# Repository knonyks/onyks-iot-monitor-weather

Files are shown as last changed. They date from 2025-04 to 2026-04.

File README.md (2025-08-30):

<span style="font-weight:700;font-size:40px; font-style: italic;">
    Stacja pogodowa
</span>

## Wstęp
Tematem tego projektu jest stacja pogodowa, która zbiera informację odnośnie warunków atmosferycznych i na ich podstawie wysyła dane na oficjalną stronę koła naukowego ONYKS. Stacja ta, mierzy takie wielkości jak poziom CO2, temperaturę, prędkość wiatru, wilgotność itp. (o tym dalej).

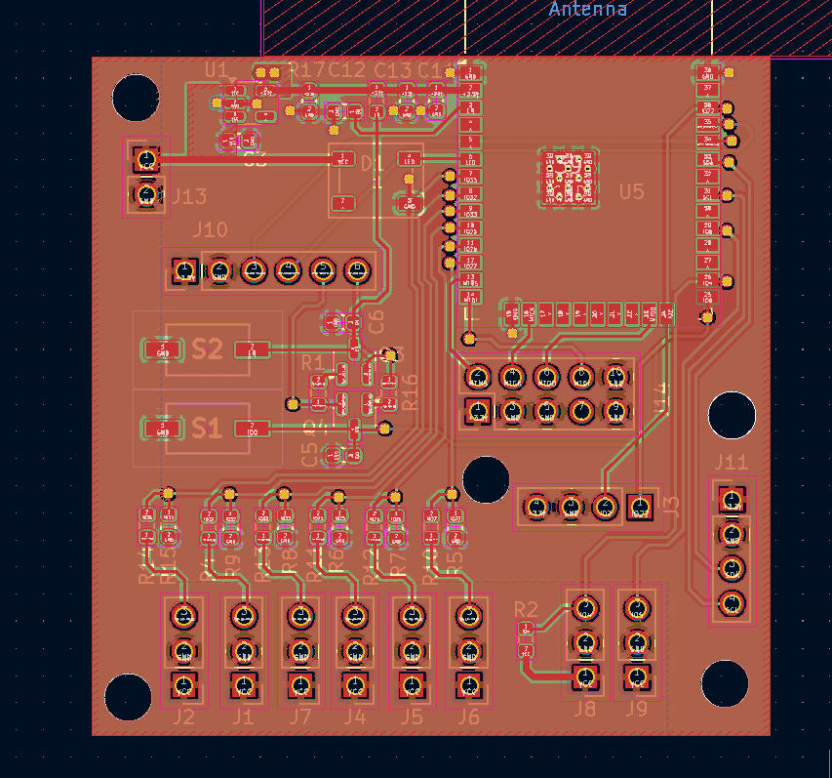
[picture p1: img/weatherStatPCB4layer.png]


## Założenia - jak to ma działać
Dane zbierane są za pomocą odpowiednich czujników a następnie przetwarzane przez mikrokontroler ESP32 - w tym projekcie użyto ESP32-WROOM-32D. Po przetworzeniu dane będą wysyłane na serwer przy użyciu WIFI, a następnie wyświetlane w odpowiedniej rubryce na głównej stronie koła naukowego ONYKS. Planowany rozmiar PCB ***100 mm x 82 mm***.

## Pomiary 

- Pomiar prędkości wiatru - polega na zmierzeniu prędkości obrotowej wału z magnesem, który jest obracany przy użyciu wiatraka. Pomiar ten będzie wykonywany za pomocą **Hallotronu** (czyli na przykład pomiar częstotliwości umownej "1" na czujniku i na podstawie tego określenie prędkości).

- Pomiar ilości opadów - wykonywany w podobny sposób co pomiar prędkości wiatru, z tą różnicą, że wałem kręcą łopatki, o konkretnej objętości. Takie koło wodne wporowadzane jest w ruch kiedy dana łopatka jest wypełniona. Obroty wału z magnesem są szczytywane za pomocą **Hallotronu**. 

- Pomiar kierunku wiatru - odbywa się również za pomocą 4 **Hallotronów** i wału obracanego wiatrowskazem. Tym razem aktywne czujniki wskazują kierunek. Do wskazania będzie 8 kierunków (na przykład pólnoc, południowy wschód itd.).

- Pomiar temperatury oraz wilgotności powietrza - odczytywane dane są z czujnika **DHT22**, który jest zamontowany w obudowie na zewnątrz stacji.

- Pomiar stężenia C02 w atmosferze - odbywa się za pomocą czujnika **SEN0219** znajdującego się bezpośrednio na PCB.

- Pomiar jakości powietrza - polega zastosowaniu czujnika **MQ135**, który jest czuły na Amoniak, gazy Siarczku, opary spowodowane spalaniem Benzenu, oraz potrafi wykrywać dym i innego rodzaju szkodliwe gazy. W czystym powietrzu czujnik ten ma niską przewodność, rośnie wraz z pojawieniem się w atmosferze substancji szkodliwych

## Obudowy oraz elementy mechaniczne

- Obudowy, będą zaprojektowane w oprogramowaniu CAD a następnie wyprodukowane za pomocą druku 3D. 

- Wały i łożyska będą kupowane w sklepie modelarskim np. *https://sklep.modelarnia.pl/*, lub budowalnym takim jak OBI czy CASTORAMA.

- Wiatrak i koło wodne będą zaprojektowane w oprogramowaniu CAD, a następnie drukowane.

- Do **Hallotronów** będą użyte drobne magnesy Neodymowe

## Schematy blokowe

###  Położenie elementów na płytce drukowanej :
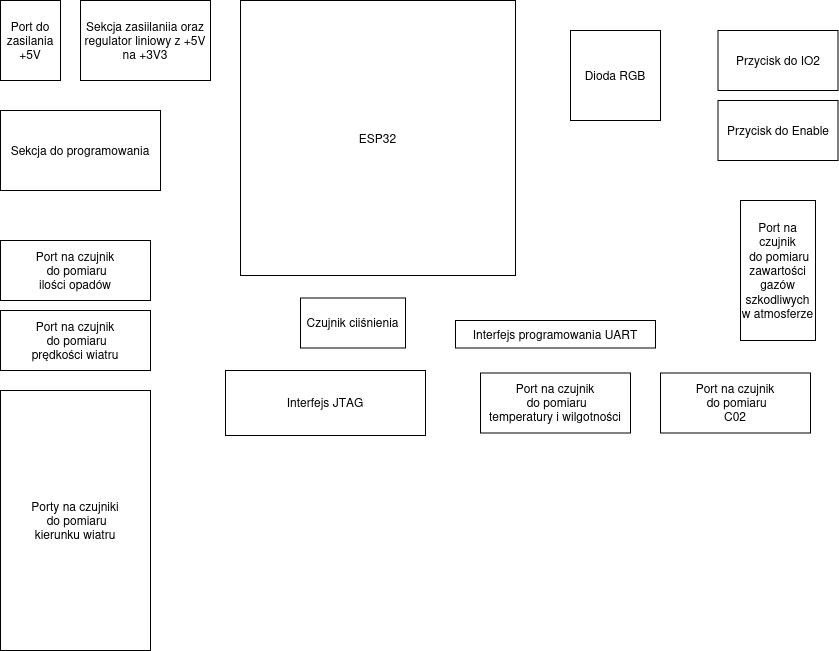
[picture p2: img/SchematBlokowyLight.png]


###  Ogólny schemat ideowy układu :
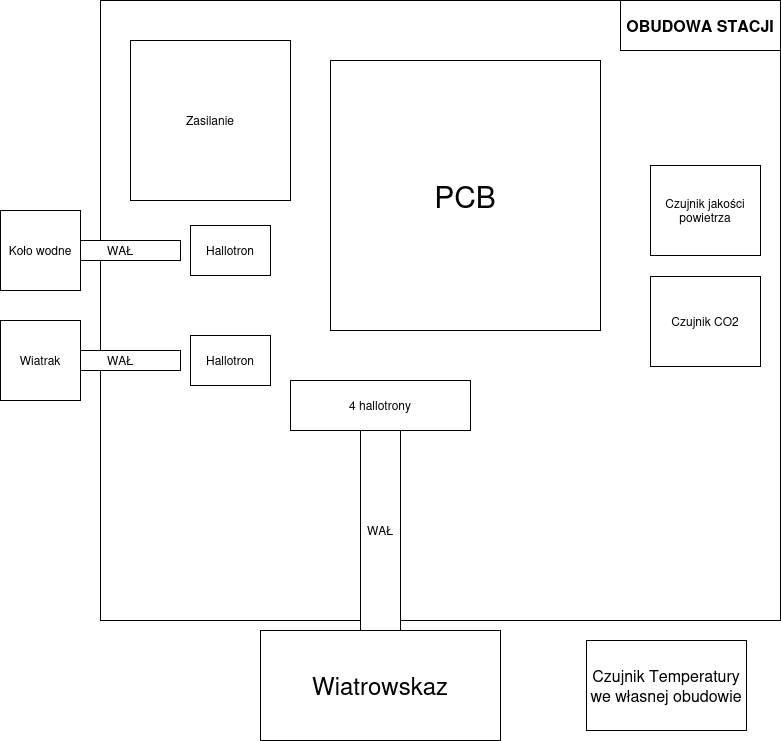
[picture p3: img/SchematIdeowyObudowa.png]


## Link do rozpiski z elementami
Tutaj stworzony jest wykaz elementów potrzebnych do złożenia danej stacji : 
https://docs.google.com/spreadsheets/d/16E9U7lwzSHfPhs8wRjM2mrblf8zyNPCpttjlwKn6Azs/edit?usp=sharing

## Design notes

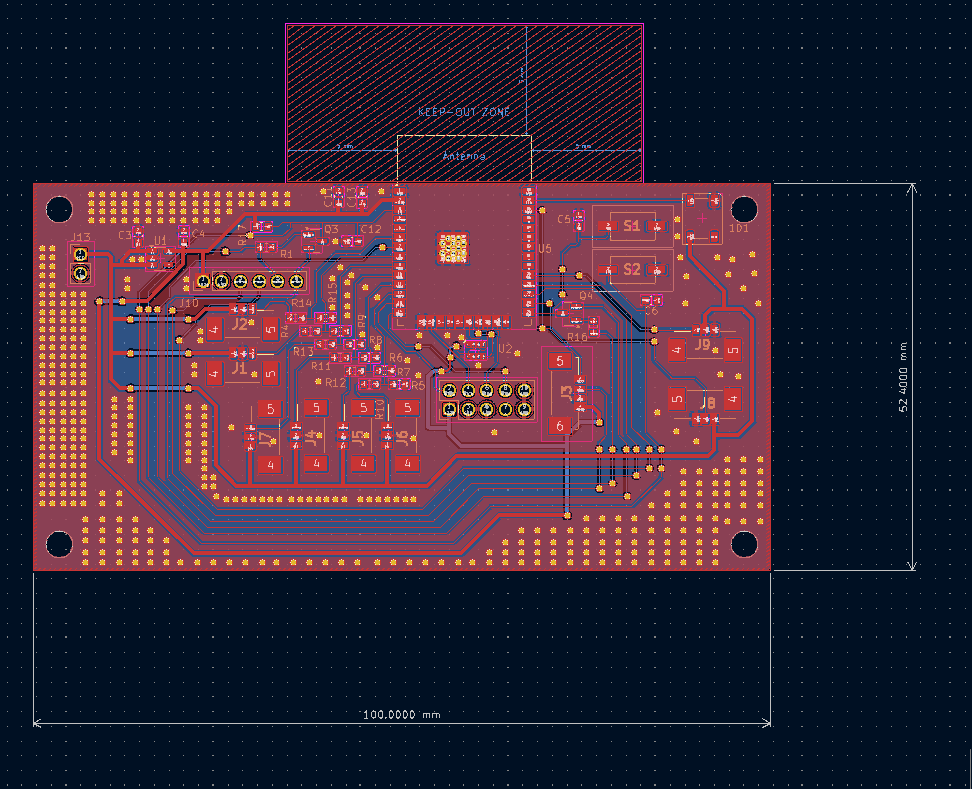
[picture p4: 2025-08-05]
img/PCBdims3.png

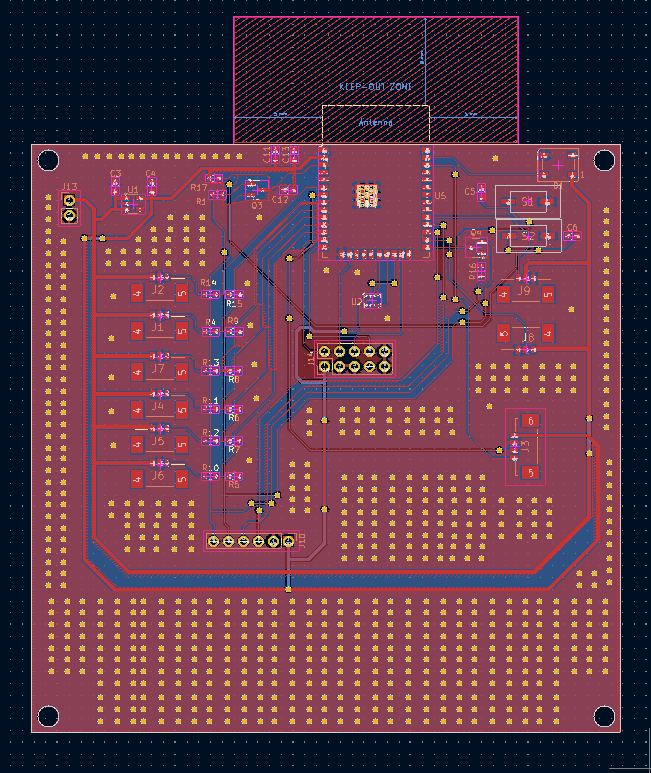
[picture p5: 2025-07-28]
img/PCBDimensions2.png

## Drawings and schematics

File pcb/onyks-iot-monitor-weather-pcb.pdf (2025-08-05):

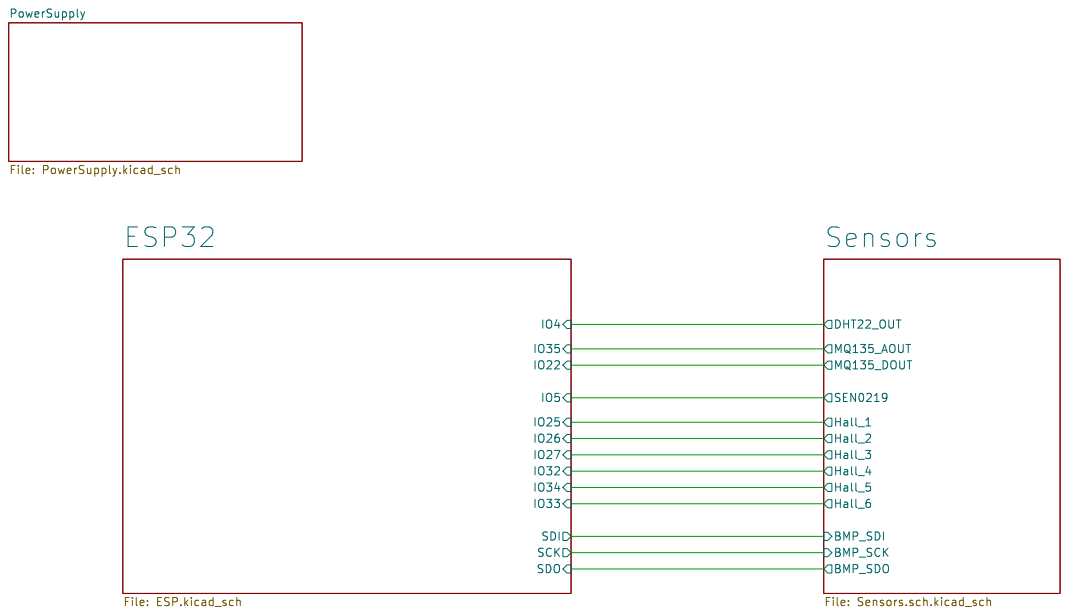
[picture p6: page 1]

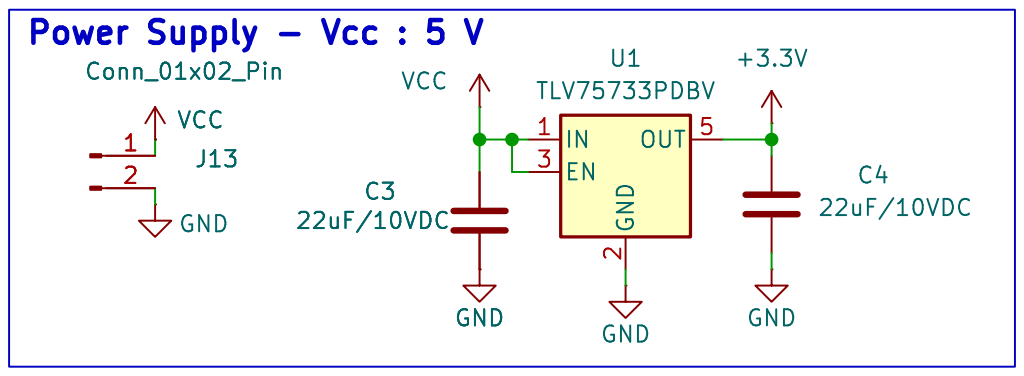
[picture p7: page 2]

VCC Power Supply - Vcc : 5 V

Id: 5/4 Title: File: PowerSupply.kicad_sch Sheet: /PowerSupply/

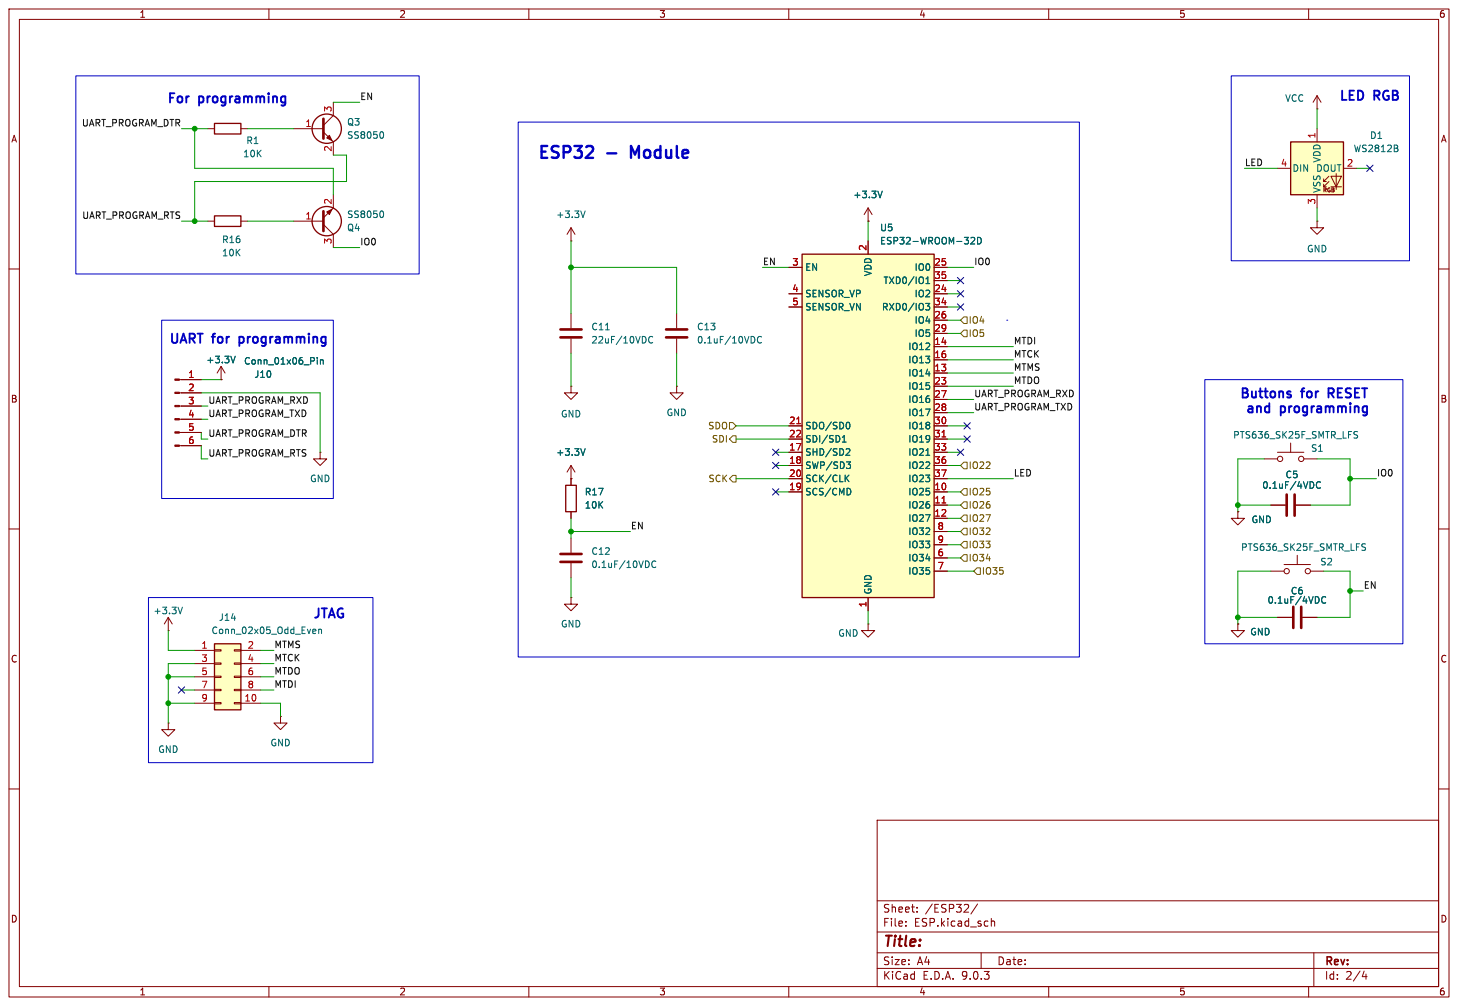
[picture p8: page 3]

Id: 2/4 Title: File: ESP.kicad_sch Sheet: /ESP32/ GND

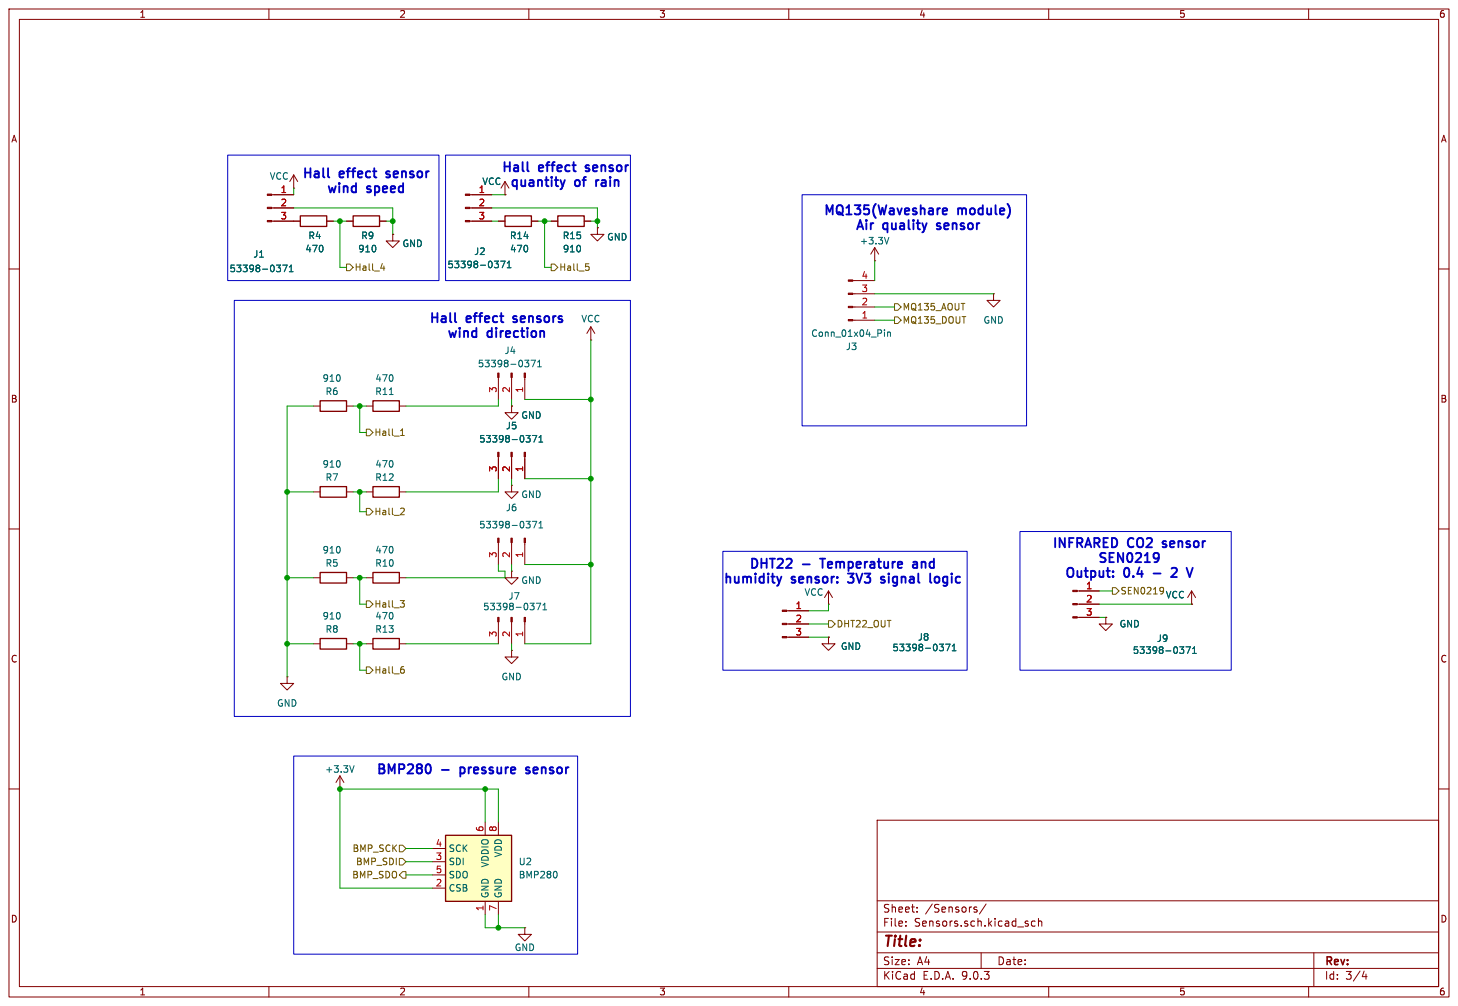
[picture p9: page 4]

Air quality sensor DHT22 - Temperature and

Hall effect sensors wind direction

humidity sensor: 3V3 signal logic

Id: 3/4 Title: File: Sensors.sch.kicad_sch Sheet: /Sensors/

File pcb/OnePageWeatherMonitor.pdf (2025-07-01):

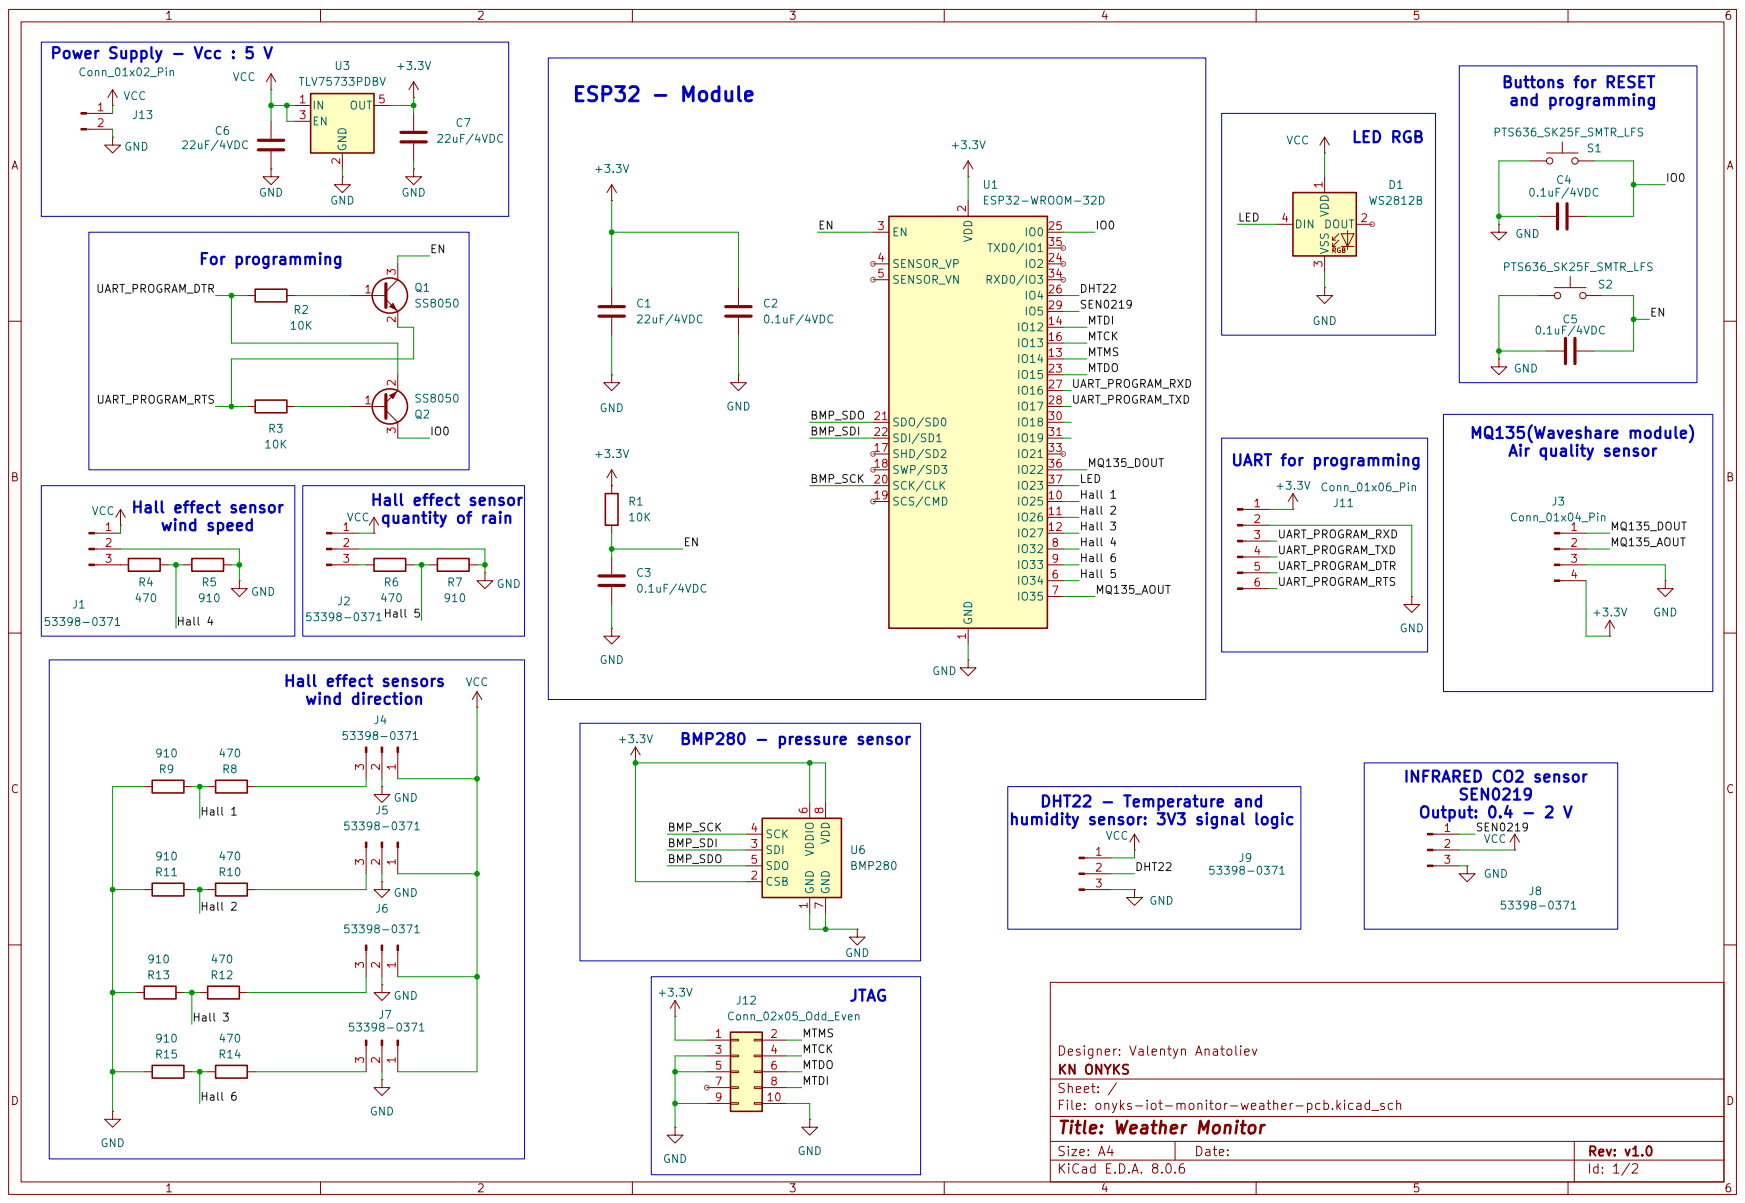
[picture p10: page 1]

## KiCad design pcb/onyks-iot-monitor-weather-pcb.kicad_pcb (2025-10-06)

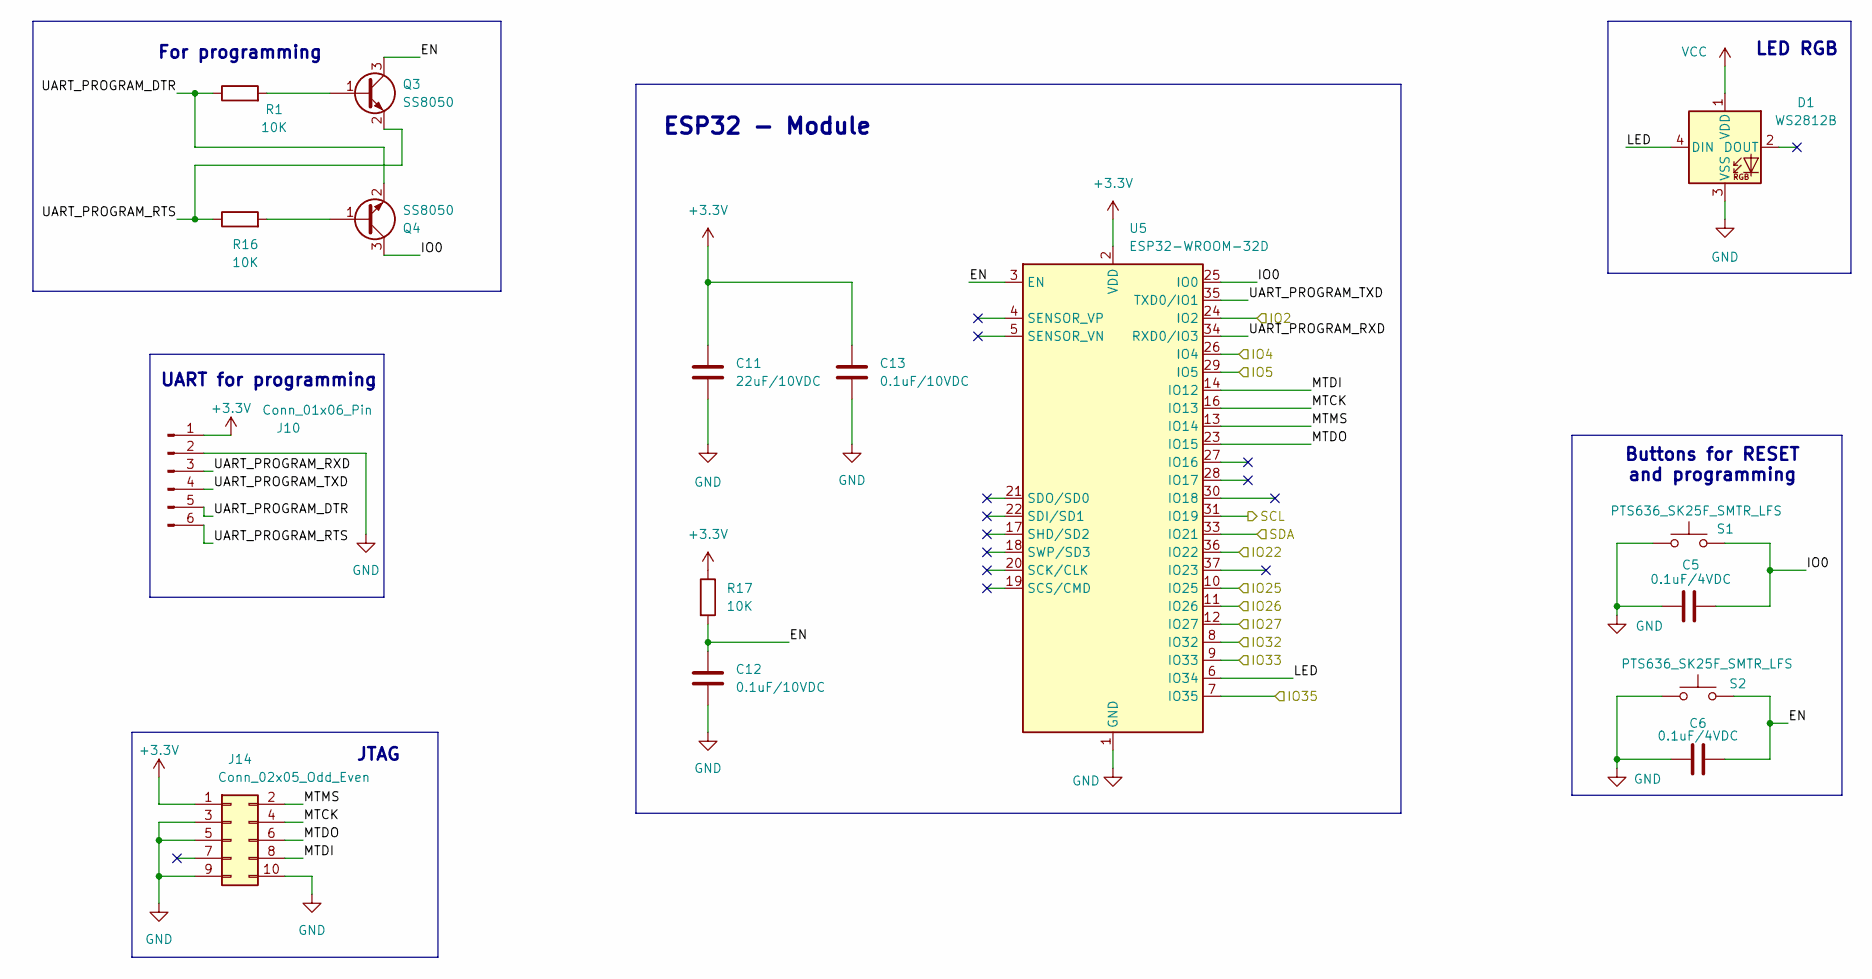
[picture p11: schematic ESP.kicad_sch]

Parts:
C5, C6: 0.1uF/4VDC; C_0603_1608Metric
C11: 22uF/10VDC; C_0603_1608Metric
C12, C13: 0.1uF/10VDC; C_0603_1608Metric
D1: WS2812B; LED_WS2812B_PLCC4_5.0x5.0mm_P3.2mm
J10: Conn_01x06_Pin; PinHeader_1x06_P2.54mm_Vertical
J14: Conn_02x05_Odd_Even; PinHeader_2x05_P2.54mm_Vertical
Q3, Q4: SS8050; SOT-23
R1, R16, R17: 10K; R_0603_1608Metric
S1, S2: PTS636_SK25F_SMTR_LFS; PTS636SK25FSMTRLFS; Mouser Part Number 611-PTS636SK25FSMTRL
U5: ESP32-WROOM-32D

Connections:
+3.3V: C11.1, C13.1, J10.1, J14.1, R17.1, U5.2 (VDD); also elsewhere on the board
/ESP32/EN: C6.2, C12.1, Q3.3 (C), R17.2, S2.2, U5.3 (EN)
/ESP32/IO0: C5.2, Q4.3 (C), S1.2, U5.25 (IO0)
/ESP32/IO2: U5.24 (IO2); also elsewhere on the board
/ESP32/IO4: U5.26 (IO4); also elsewhere on the board
/ESP32/IO5: U5.29 (IO5); also elsewhere on the board
/ESP32/IO22: U5.36 (IO22); also elsewhere on the board
/ESP32/IO25: U5.10 (IO25); also elsewhere on the board
/ESP32/IO26: U5.11 (IO26); also elsewhere on the board
/ESP32/IO27: U5.12 (IO27); also elsewhere on the board
/ESP32/IO32: U5.8 (IO32); also elsewhere on the board
/ESP32/IO33: U5.9 (IO33); also elsewhere on the board
/ESP32/IO35: U5.7 (IO35); also elsewhere on the board
/ESP32/LED: D1.4 (DIN), U5.6 (IO34)
/ESP32/MTCK: J14.4, U5.16 (IO13)
/ESP32/MTDI: J14.8, U5.14 (IO12)
/ESP32/MTDO: J14.6, U5.23 (IO15)
/ESP32/MTMS: J14.2, U5.13 (IO14)
/ESP32/SCL: U5.31 (IO19); also elsewhere on the board
/ESP32/SDA: U5.33 (IO21); also elsewhere on the board
/ESP32/UART_PROGRAM_DTR: J10.5, Q4.2 (E), R1.1
/ESP32/UART_PROGRAM_RTS: J10.6, Q3.2 (E), R16.1
/ESP32/UART_PROGRAM_RXD: J10.3, U5.34 (RXD0/IO3)
/ESP32/UART_PROGRAM_TXD: J10.4, U5.35 (TXD0/IO1)
GND: C5.1, C6.1, C11.2, C12.2, C13.2, D1.3 (VSS), J10.2, J14.3, J14.5, J14.9, J14.10, S1.1, S2.1, U5.1 (GND), U5.15 (GND), U5.38 (GND), U5.39 (GND); also elsewhere on the board
unnamed: Q3.1 (B), R1.2
unnamed: Q4.1 (B), R16.2
VCC: D1.1 (VDD); also elsewhere on the board

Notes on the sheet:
ESP32 - Module
JTAG
UART for programming
LED RGB
Buttons for RESET and programming
For programming

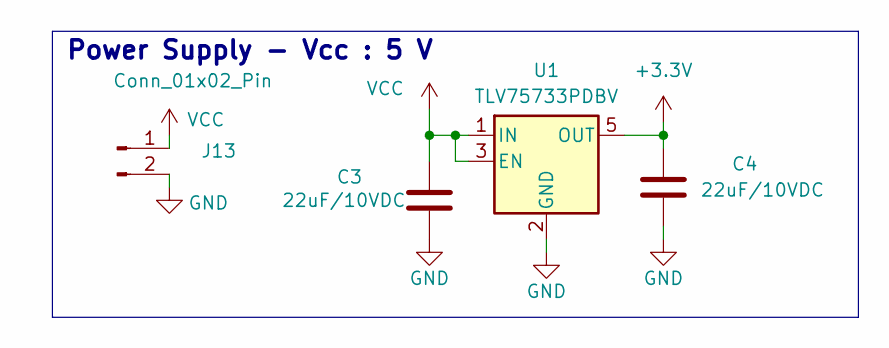
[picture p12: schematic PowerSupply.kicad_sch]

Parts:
C3, C4: 22uF/10VDC; C_0603_1608Metric
J13: Conn_01x02_Pin; PinHeader_1x02_P2.54mm_Vertical
U1: TLV75733PDBV; SOT-23-5

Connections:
+3.3V: C4.1, U1.5 (OUT); also elsewhere on the board
GND: C3.2, C4.2, J13.2, U1.2 (GND); also elsewhere on the board
VCC: C3.1, J13.1, U1.1 (IN), U1.3 (EN); also elsewhere on the board

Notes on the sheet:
Power Supply - Vcc : 5 V

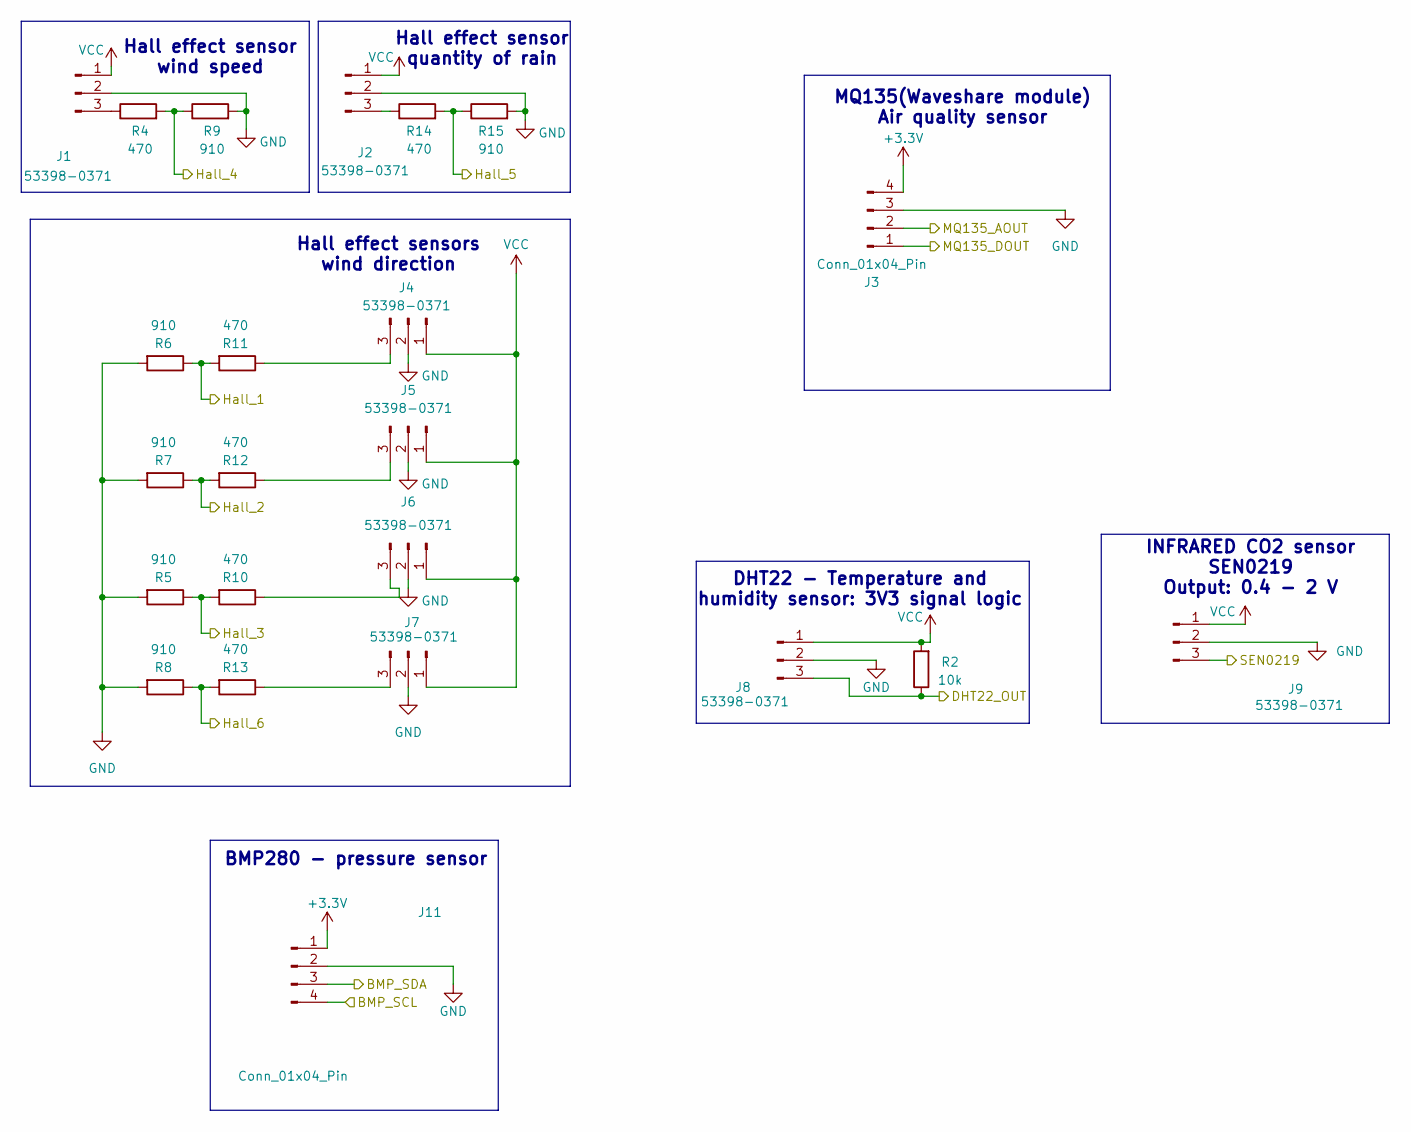
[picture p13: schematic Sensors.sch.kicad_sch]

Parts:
J1, J2, J4, J5, J6, J7, J8, J9: 53398-0371; PinHeader_1x03_P2.54mm_Vertical; Manufacturer_Part_Number 53398-0371
J3, J11: Conn_01x04_Pin; PinHeader_1x04_P2.54mm_Vertical
R2: 10k; R_0603_1608Metric
R4, R10, R11, R12, R13, R14: 470; R_0603_1608Metric
R5, R6, R7, R8, R9, R15: 910; R_0603_1608Metric

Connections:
+3.3V: J3.4, J11.1; also elsewhere on the board
/ESP32/IO2: J3.2; also elsewhere on the board
/ESP32/IO4: J8.3, R2.1; also elsewhere on the board
/ESP32/IO5: J9.3; also elsewhere on the board
/ESP32/IO22: J3.1; also elsewhere on the board
/ESP32/IO25: R6.1, R11.2; also elsewhere on the board
/ESP32/IO26: R7.1, R12.2; also elsewhere on the board
/ESP32/IO27: R5.1, R10.2; also elsewhere on the board
/ESP32/IO32: R4.2, R9.1; also elsewhere on the board
/ESP32/IO33: R8.1, R13.2; also elsewhere on the board
/ESP32/IO35: R14.2, R15.1; also elsewhere on the board
/ESP32/SCL: J11.4; also elsewhere on the board
/ESP32/SDA: J11.3; also elsewhere on the board
GND: J1.2, J2.2, J3.3, J4.2, J5.2, J6.2, J7.2, J8.2, J9.2, J11.2, R5.2, R6.2, R7.2, R8.2, R9.2, R15.2; also elsewhere on the board
unnamed: J1.3, R4.1
unnamed: J2.3, R14.1
unnamed: J4.3, R11.1
unnamed: J5.3, R12.1
unnamed: J6.3, R10.1
unnamed: J7.3, R13.1
VCC: J1.1, J2.1, J4.1, J5.1, J6.1, J7.1, J8.1, J9.1, R2.2; also elsewhere on the board

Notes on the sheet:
Hall effect sensors wind direction
INFRARED CO2 sensor SEN0219 Output: 0.4 - 2 V
BMP280 - pressure sensor
DHT22 - Temperature and humidity sensor: 3V3 signal logic
MQ135(Waveshare module) Air quality sensor
Hall effect sensor wind speed
Hall effect sensor quantity of rain

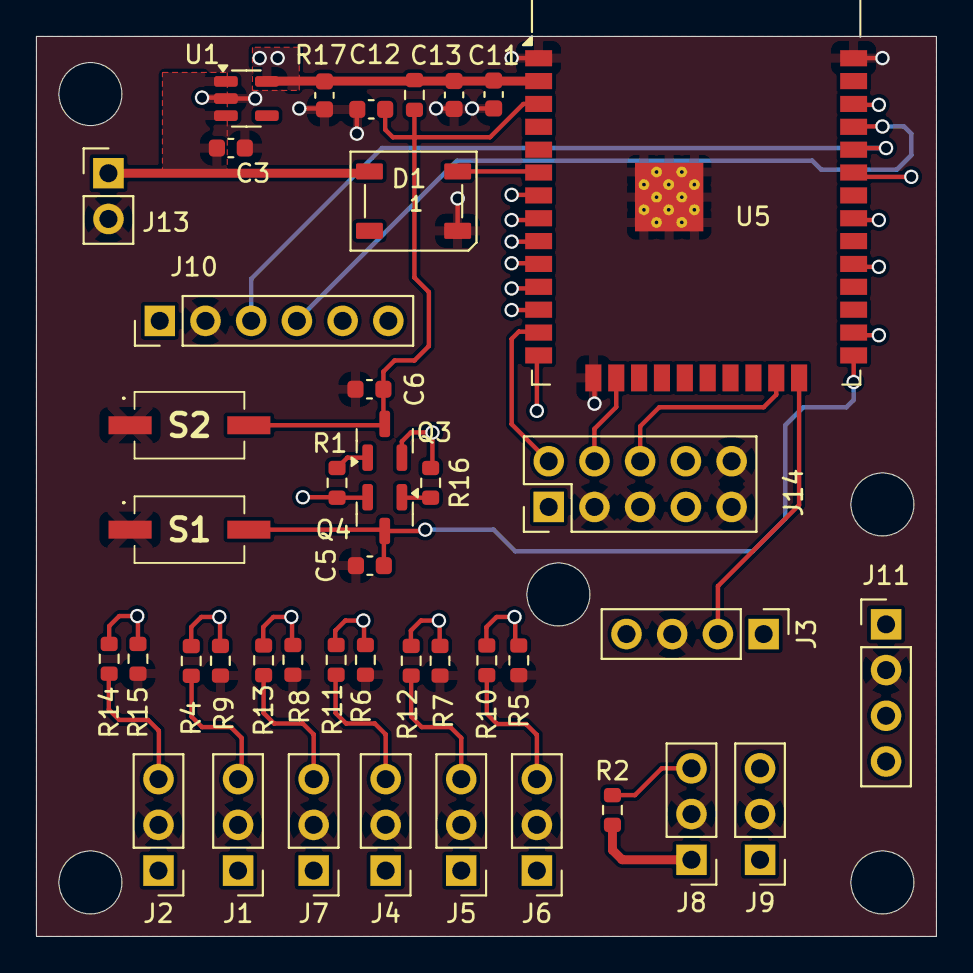
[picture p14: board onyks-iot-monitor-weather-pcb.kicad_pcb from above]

Board: 4 copper layers, 50.0 x 50.0 mm, 43 parts (0 on the bottom side), 34 nets.

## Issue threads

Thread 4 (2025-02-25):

PCB check

PodrickKing, 2025-02-25:
Hi, can you please check if my PCB is ok? Thank you in advance!

przemech, 2025-02-25:
1. Are the dimensions of the board related to some enclosure? Or are these just free dimensions?
2. Do you have any enclosure or you need a help to get one? (We can help)
3. Don't connect any GND pads. Use a filled zone. At this moment you have a bottom layer of GND zone. Now you can select it, right-click, select "Zones" -> "Duplicate Zone onto Layer...". A window should open - select the F.Cu layer and click "OK". Then you can either refill it from menu or by pressing "B" (if you have a default key mapping).
4. Empty zones should be filled with "Via Stitching". You can do it manually or better - with a plugin, however it is one of the easiest final steps, so there is no need to do it for now.
5. Pay attention to the purpose of each components. For example C1 and C2 are decoupling and filtering capacitors, so you should place them as close as possible to ES32 power input - C2 the closest to the ESP32 pad and C1 just behind C2.

For this moment try to fix these problems. Probably after that, the layout with change dramatically,

Closed 2025-03-17.

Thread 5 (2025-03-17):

Uwagi - checklist

przemech, 2025-03-17:
Uniwersalne uwagi - checklist:

- [ ] [Hierarchiczna struktura schematu](https://docs.kicad.org/master/en/eeschema/eeschema.html#hierarchical-schematics) - root same sheety
- [ ] Global Label -> Net Label (lokalne)
- [ ] Global Label -> Hierarchical Label (między schematami)
- [ ] No Connect Flags dla niepodłączoncych pinów
- [ ] Czytanie schematów od lewej do prawej -> np. zasilanie po lewej i odbiorca po prawej
- [ ] Zbyt dokładne wartości elementów (zbyt dokładny szereg)
- [ ] Nazwa modelu cewki do symbolu  jako kolejny field
- [ ] Napięcia przy kondensatorach np. 10u -> 10n/10V
- [ ] Obudowy SMD 0603 (ew. dla kondesnatorów o dużych pojemnościach 0805)
- [ ] Przy złączu zasilania opis zakresu napięcia i maksymalny prąd

Do tego projektu:
- skupić się na razie tylko na schemacie
- zrobić na podstawie powyższej checklisty aktualizację schematu

Closed 2025-07-06.

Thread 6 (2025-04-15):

Lista "TODO" etapów projektu

Xenon02, 2025-04-15:
### Wstępne działania projektowe

- [ ] Wykonanie schematu blokowego urządzenia (w README lub w oddzielnym pliku tekstowym/graficznym)
- [ ] Dobranie elementów i sporządzenie listy elementów w Excelu
- [ ] Poddanie tego schematu blokowego do weryfikacji (oznaczenie w issue) @przemech i/lub @Xenon02

### Sporządzenie układu elektronicznego

- [ ] [Hierarchiczna struktura schematu](https://docs.kicad.org/master/en/eeschema/eeschema.html#hierarchical-schematics)
- [ ] Global Label -> Net Label (lokalne)
- [ ] Global Label -> Hierarchical Label (między schematami)
- [ ] No Connect Flags dla niepodłączoncych pinów
- [ ] Czytanie schematów od lewej do prawej -> np. zasilanie po lewej i odbiorca po prawej
- [ ] Zbyt dokładne wartości elementów (zbyt dokładny szereg)
- [ ] Nazwa modelu cewki do symbolu  jako kolejny field
- [ ] Napięcia przy kondensatorach np. 10u -> 10n/10V
- [ ] Obudowy SMD 0603 (ew. dla kondesnatorów o dużych pojemnościach 0805)
- [ ] Przy złączu zasilania opis zakresu napięcia i maksymalny prąd

-[ ] Poddanie tego schematu elektronicznego do weryfikacji (oznaczenie w issue) @przemech

### Lista do wykonania płytki PCB będzie później wykonana i zaktualizowana. W razie wcześniejszego działania zapraszam do obejrzenia : (https://www.youtube.com/watch?v=UhMvmdq2B5E)

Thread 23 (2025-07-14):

Review

przemech, 2025-07-14:
- [x] Przyciski wrzucić do programing & debugging, chociaż nawet najlepiej by było ESP32 połączyć z programming and debugging, a power supply jako osobno. LED RGB można by wrzucić do Sensors jako Peripherals, albo dodać ją do ESP32 jako, że ma być głównie wykorzystywana do debuggingu.
- [x] Tutaj może być bokiem ten symbol zasilania, choć najlepiej by było zrobić odbicie lustrzane w poziomie i wtedy już zasilanie będzie ustawione pionowo:

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

- [x] Przy kondensatorach to można wpisać wartość 10VDC (typowa wartość) zamiast 4VDC

przemech, 2025-07-15:
Teraz jest już lepiej

Closed 2025-07-15.

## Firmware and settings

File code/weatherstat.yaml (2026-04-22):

esphome:
  name: weatherstat
  friendly_name: weatherstat

esp32:
  board: esp32dev
  framework:
    type: arduino


# Enable logging
logger:

# Enable Home Assistant API
api:
  encryption:
    key: "1jMWQU5upHFOSsau7648DkHP1Jtl0ZQv9BIFX6xRODI="

light:
- platform: neopixelbus
  type: GRB
  variant: WS2812
  pin: 23
  num_leds: 1        # <-- change to your LED count
  name: "WS2812B Strip"
  method: esp32_rmt   # REQUIRED for ESP-IDF

uart:
  id: uart_pms
  rx_pin: GPIO22   # PMS5003 TX
  tx_pin: GPIO2    # PMS5003 RX (optional)
  baud_rate: 9600

sensor:
  - platform: adc
    pin: 35
    name: "CO2 Sensor (Analog)"
    attenuation: 11db
    update_interval: 2s
    filters:
      - multiply: 3.3
      - calibrate_linear:
          - 0.4 -> 400
          - 2.0 -> 5000
    unit_of_measurement: "ppm"

  - platform: pmsx003
    type: PMSX003
    uart_id: uart_pms
    pm_1_0:
      name: "PM1.0"
    pm_2_5:
      name: "PM2.5"
    pm_10_0:
      name: "PM10"
    update_interval: 30s
ota:
  - platform: esphome
    password: "123104f93f2be837ac4baf32ac84cf4d"

wifi:
  ssid: !secret wifi_ssid
  password: !secret wifi_password

  # Enable fallback hotspot (captive portal) in case wifi connection fails
  ap:
    ssid: "Weatherstat Fallback Hotspot"
    password: "e2dRvPe49NrA"

captive_portal:

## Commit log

2024-11-14 Added Readme. Created pcb blank project
    [onyks-iot-esp32-template.kicad_pcb, onyks-iot-esp32-template.kicad_sch, onyks-iot-monitor-weather-pcb.kicad_pcb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]
2024-11-17 Added Docs for sensors and esp32wroom32d
2024-11-18 basic PCB template layout from the last meeting
    [onyks-iot-monitor-weather-pcb.kicad_sch]
2024-11-24 Added schematic for our project
    [onyks-iot-monitor-weather-pcb.kicad_pcb, onyks-iot-monitor-weather-pcb.kicad_sch]
2024-12-01 Updated schematics and added footprints and 3dmodels for the elements
    [1825910-6.SchLib, 1825910-6.stp, 18259106.PcbLib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]
2024-12-02 Added PCBv1.0
    [old_bad.kicad_pcb, onyks-iot-monitor-weather-pcb.kicad_sch]
2024-12-08 Updated schematic, changed and added couple of elements: 1.Changed buttons; 2.Changed Voltage Regulator; 3.Changed LED; 4.Added JTAG interface; 5.Added UART for programming; 6.Added other elements li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
    [EDI2CAP.CFG, PTS636_SK25F_SMTR_LFS.stp, chips.prt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]
2024-12-16 Done my version of PCB
    [onyks-iot-monitor-weather-pcb.kicad_pcb, onyks-iot-monitor-weather-pcb.kicad_sch]
2024-12-17 Few corrections, small ammount of parts were not connected to the ground.
    [onyks-iot-monitor-weather-pcb.kicad_pcb]
2025-01-03 Changed ground planes, and overall small changes
    [onyks-iot-monitor-weather-pcb.kicad_pcb]
2025-02-19 CheckedJLCPCBDesignRules, the only remaining errors are due to holes in esp 32 module
    [onyks-iot-monitor-weather-pcb.kicad_pcb, onyks-iot-monitor-weather-pcb.kicad_sch]
2025-02-20 Mistake Correction
    [onyks-iot-monitor-weather-pcb.kicad_pcb]
2025-02-26 U6,J3 ground pads are not connected to the ground zone automatically(due to their footprints). Ground pads C2 and C1 are connected to the ground plane via route. Overall little changes in layout. Gro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
    [onyks-iot-monitor-weather-pcb.kicad_pcb]
2025-02-28 Changed c1 c2 positions
    [onyks-iot-monitor-weather-pcb.kicad_pcb]
2025-02-28 Design Rules - Thermal relief problem partially solved
    [onyks-iot-monitor-weather-pcb.kicad_pcb]
2025-02-28 beta v1
    [onyks-iot-monitor-weather-pcb.kicad_pcb]
2025-04-22 Aded Readme, change schematic layout, added block diagrams
    [old_bad.kicad_pcb, onyks-iot-monitor-weather-pcb.kicad_pcb, onyks-iot-monitor-weather-pcb.kicad_sch]
2025-06-20 Poprawki w schemacie elektrycznym
    [onyks-iot-monitor-weather-pcb.kicad_pcb, onyks-iot-monitor-weather-pcb.kicad_sch]
2025-06-23 Dalsze zmiany w schemacie elektrycznym - przewidywane duże zmiany w PCB
    [onyks-iot-monitor-weather-pcb.kicad_pcb, onyks-iot-monitor-weather-pcb.kicad_sch]
2025-07-05 Struktura hierarchiczna
    [PowerSupplyESP.kicad_sch, Programming.kicad_sch, Sensors.sch.kicad_sch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]
2025-07-15 Drobne poprawki w schemacie elektrycznym
    [ESP.kicad_sch, PowerSupply.kicad_sch, Programming.kicad_sch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]
2025-07-15 poprawiony schemat w pdf
    [ESP.kicad_sch, onyks-iot-monitor-weather-pcb.kicad_sch]
2025-07-28 zrobiony PCB
    [onyks-iot-monitor-weather-pcb.kicad_pcb]
2025-07-28 PCB poprawki, oraz znowe zrzut ekranu z PCB
    [PowerSupplyESP.kicad_sch, onyks-iot-monitor-weather-pcb.kicad_pcb]
2025-08-05 PCB poprawione
    [ESP.kicad_sch, PowerSupply.kicad_sch, Sensors.sch.kicad_sch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]
2025-08-24 PCB jeszcze mniejsza wersja
    [ESP.kicad_sch, Sensors.sch.kicad_sch, onyks-iot-monitor-weather-pcb.kicad_pcb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]
2025-08-30 4 layer PCB
    [ESP.kicad_sch, Sensors.sch.kicad_sch, onyks-iot-monitor-weather-pcb.kicad_pcb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]
2025-08-30 readme change - new 4 layer PCB image
2025-10-06 gerbery dodane do folderu fabrication
    [onyks-iot-monitor-weather-pcb-B_Cu.gbr, onyks-iot-monitor-weather-pcb-B_Mask.gbr, onyks-iot-monitor-weather-pcb-B_Paste.gbr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]
2025-11-19 dodanie zapomnianych plików drill
    [onyks-iot-monitor-weather-pcb-NPTH.drl, onyks-iot-monitor-weather-pcb-PTH.drl]
